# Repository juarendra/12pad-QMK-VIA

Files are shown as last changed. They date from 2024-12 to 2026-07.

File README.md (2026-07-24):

<div align="center">

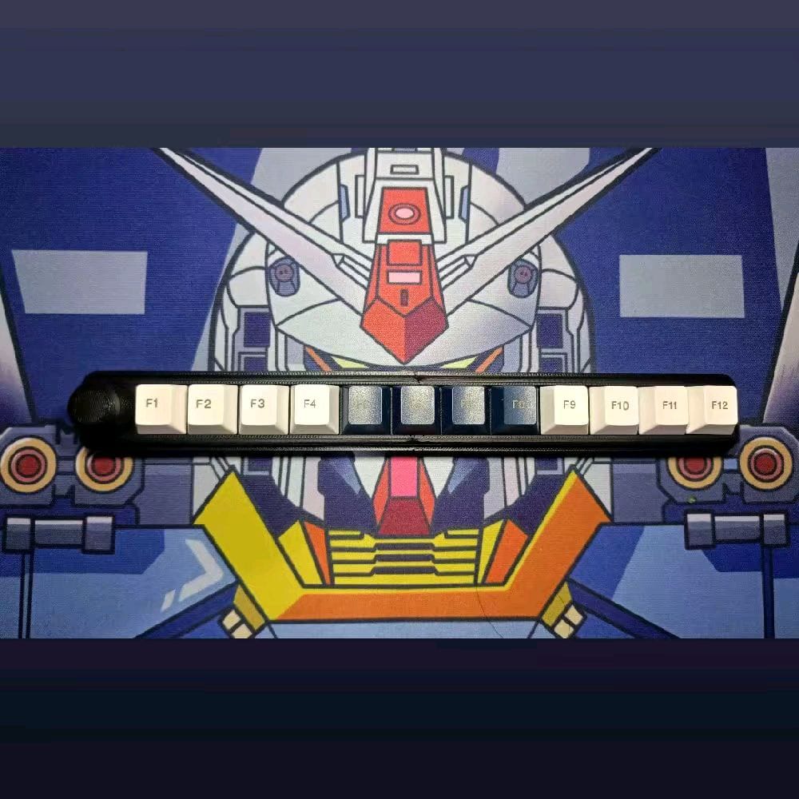
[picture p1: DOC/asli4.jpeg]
Macropad 12pad


# 12pad

**Macropad 12 tombol hotswap + knob putar — semua tombol bisa diprogram lewat VIA, tanpa driver, tanpa coding.**

oleh [Positron Electronic](https://github.com/juarendra)







[⬇️ Unduh Firmware](https://github.com/juarendra/12pad-QMK-VIA/releases/latest) ·
[📖 Buku Panduan](DOC/Buku%20Panduan%2012pad.pdf) ·
[🎛️ Buka VIA](https://usevia.app) ·
[🔌 Wiring](DOC/WIRING%20MACROPAD%2012PAD%20BY%20POSITRON%20ELEKTRONIK.drawio.pdf)

</div>

---

## ✨ Fitur

| | |
|---|---|
| ⌨️ **12 tombol hotswap** | Ganti switch tanpa solder |
| 🎚️ **Knob rotary encoder** | Putar = scroll/volume, tekan = pindah layer — bebas diatur |
| 🌈 **RGB per tombol** | 40+ efek, atur dari VIA atau langsung dari macropad (Layer 5) |
| 🧠 **6 layer × 32 macro** | Profil per aplikasi, tersimpan di dalam macropad |
| 🔧 **QMK + VIA** | Atur keymap real-time di [usevia.app](https://usevia.app), tanpa install apa pun |
| 🔌 **STM32F401 · USB-C** | WeAct Blackpill, identitas USB resmi `0x1209:0x2012` |

<div align="center">
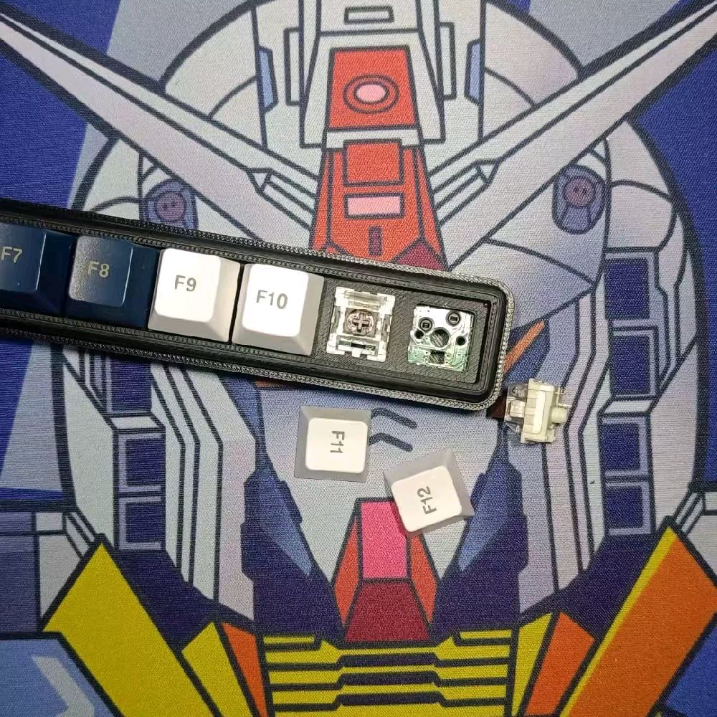
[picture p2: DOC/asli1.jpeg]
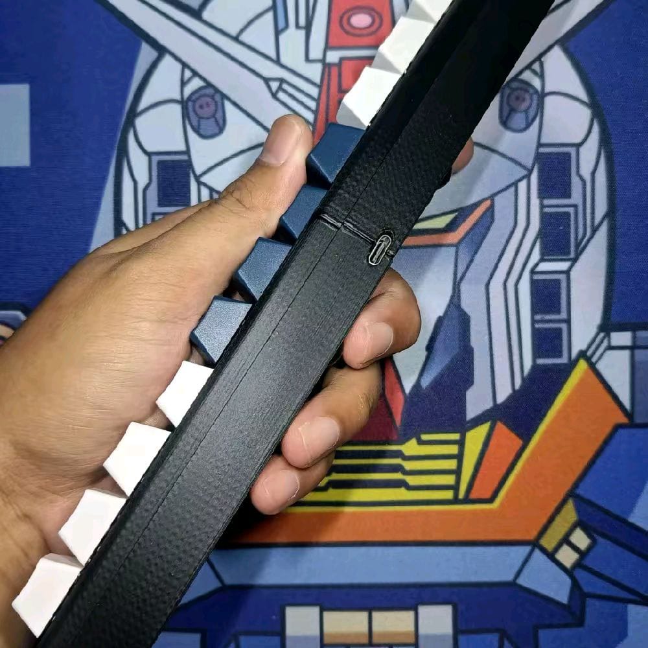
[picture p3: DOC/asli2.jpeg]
 
</div>

## 🚀 Mulai dalam 3 langkah

1. **Colok USB-C** — langsung dikenali sebagai keyboard, tanpa driver
2. **Buka [usevia.app](https://usevia.app)** di Chrome/Edge (internet menyala)
3. **Klik & atur** — pilih tombol di layar, ganti fungsinya, tersimpan otomatis di macropad

> VIA belum mendeteksi? Lihat [Load JSON File](#-load-json-file-sideload) di bawah.

📖 Panduan lengkap (peta layer, macro, RGB, troubleshooting): **[Buku Panduan 12pad (PDF)](DOC/Buku%20Panduan%2012pad.pdf)**

## ⌨️ Keymap bawaan

Tekan knob untuk berpindah layer (0 → 1 → … → 5 → 0).

| Layer | Isi |
|---|---|
| **0** | `F1`–`F12` — siap dipetakan ke shortcut aplikasi · putar knob = Page Up/Down |
| **1–4** | Kosong (transparan) — kanvas bebas untuk profil per aplikasi |
| **5** | Panel kontrol RGB: on/off, efek, kecepatan, saturasi, hue, kecerahan |

## 📦 Firmware

**Unduh siap pakai:** [**Releases — versi terbaru**](https://github.com/juarendra/12pad-QMK-VIA/releases/latest)

| File | Untuk |
|---|---|
| `handwired_positron_12pad_via.bin` | ✅ **Pengguna STM32F401** — VIA aktif |
| `handwired_positron_12pad_default.bin` | STM32F401, keymap default tanpa VIA |
| `12pad_rp2040_default.uf2` | Varian RP2040 |

<details>
<summary><b>Cara flash (STM32)</b></summary>

1. Masuk bootloader: cabut USB, **tahan knob**, colok USB — atau tahan tombol `BOOT0` di board saat colok USB
2. Buka [QMK Toolbox](https://github.com/qmk/qmk_toolbox/releases) → Open file `.bin` → **Flash**

Atau lewat terminal:

```sh
dfu-util -a 0 -d 0483:df11 -s 0x08000000:leave -D handwired_positron_12pad_via.bin
```

Setelah flash, identitas USB berubah menjadi **"Positron Electronic 12pad"** — load ulang `12pad_via_definitions.json` terbaru di VIA bila sebelumnya pernah sideload.
</details>

<details>
<summary><b>Build dari source</b></summary>

Source keyboard: [`FIRMWARE/handwired/positron/12pad/`](FIRMWARE/handwired/positron/12pad). Salin ke `qmk_firmware/keyboards/handwired/positron/12pad`, lalu:

```sh
qmk compile -kb handwired/positron/12pad -km via
```

Setiap push ke folder firmware juga dibuild otomatis oleh [GitHub Actions](https://github.com/juarendra/12pad-QMK-VIA/actions) — unduh `.bin` dari artifact.
</details>

## 🎛️ VIA

### Auto detect
Colok macropad → buka [usevia.app](https://usevia.app) atau [aplikasi VIA](https://github.com/the-via/releases/releases) dengan internet aktif → terdeteksi otomatis.

### 📂 Load JSON File (sideload)
Kalau belum terdeteksi (definisi resmi masih dalam proses):

1. Colok macropad, buka VIA
2. Tab **Settings** → aktifkan **Show Design Tab**
3. Tab **Design** → **Load** file [`12pad_via_definitions.json`](12pad_via_definitions.json)
4. Buka tab **Configure** — siap diatur
5. Masih "searching"? Cabut-colok USB, ulangi dari langkah 3

### 🎚️ Setting knob
Knob tampil sebagai 3 "tombol" di VIA: putar kiri · tekan · putar kanan. Untuk kombinasi khusus pakai **Any** (kategori Special) dengan keycode QMK:

| Keycode | Hasil |
|---|---|
| `LALT(KC_TAB)` | Alt + Tab |
| `LCTL(KC_C)` | Ctrl + C |
| `LSFT(LCTL(KC_END))` | Shift + Ctrl + End |
| `MT(MOD_RSFT, KC_ENT)` | Tahan = Shift, ketuk = Enter |
| `MO(1)` / `TO(2)` | Pindah layer sementara / permanen |
| `M0` … `M31` | Jalankan macro |

Referensi: [Keycode QMK](https://docs.qmk.fm/keycodes) · [Panduan VIA](https://docs.keeb.io/via) · [Macro VIA (PDF)](DOC/MACRO%20VIA%20USAGE.pdf) · [Video tutorial](https://youtu.be/GtSeo69Y0Zw)

## 🛠️ Hardware

- [Dimensi (PDF)](HARDWARE/12pad_dimension.pdf) · [Model 3D STEP](HARDWARE/12pad.step)
- [Case 3D-printable (STL)](HARDWARE/case) — top & bottom, tersedia versi terbelah 2 untuk printer kecil
- [Wiring diagram](DOC/WIRING%20MACROPAD%2012PAD%20BY%20POSITRON%20ELEKTRONIK.drawio.pdf)

## 🗺️ Status Pendaftaran Resmi

| Tahap | Status |
|---|---|
| USB VID/PID `0x1209:0x2012` — [pid.codes #1249](https://github.com/pidcodes/pidcodes.github.com/pull/1249) | ✅ checks lulus, menunggu merge |
| QMK upstream — [qmk_firmware #26362](https://github.com/qmk/qmk_firmware/pull/26362) | ✅ CI lulus, menunggu review |
| VIA autodetect global — PR ke [the-via/keyboards](https://github.com/the-via/keyboards) | ⏳ setelah QMK merge (file sudah siap) |

## 📄 License

Firmware dilisensikan di bawah [GPL-2.0](LICENSE).

<div align="center">
<sub>Dibuat dengan ☕ oleh <b>Positron Electronic</b> · Indonesia</sub>
</div>

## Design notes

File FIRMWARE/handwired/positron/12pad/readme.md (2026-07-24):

# 12pad

12-key hotswap macropad with a rotary encoder, by Positron Electronic.

* Keyboard Maintainer: [juarendra](https://github.com/juarendra)
* Hardware Supported: WeAct Blackpill STM32F401 (USB Type-C)
* Hardware Availability: [Positron Electronic](https://github.com/juarendra/12pad-QMK-VIA)

Make example for this keyboard (after setting up your build environment):

    qmk compile -kb handwired/positron/12pad -km default

Flashing:

    qmk flash -kb handwired/positron/12pad -km default

See the [build environment setup](https://docs.qmk.fm/#/getting_started_build_tools) and the [make instructions](https://docs.qmk.fm/#/getting_started_make_guide) for more information. Brand new to QMK? Start with our [Complete Newbs Guide](https://docs.qmk.fm/#/newbs).

## Bootloader

Enter the bootloader in 3 ways:

* **Bootmagic reset**: Hold down the encoder knob (top-left key) and plug in the keyboard
* **Physical reset**: Hold the `BOOT0` button on the Blackpill, tap `NRST` (or plug in USB), then release `BOOT0`
* **Keycode in layout**: Press the key mapped to `QK_BOOT` if it is available

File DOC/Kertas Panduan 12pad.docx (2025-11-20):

1. Untuk Documentasi Lengkapnya anda dapat membuka link google drive dibawah ini

https://github.com/juarendra/12pad-QMK-VIA

Lihat dahulu video untuk mengetahui cara pengunaan macropad dengan software VIA

2. Fungsi file file di google drive
  a. Link Keycode.txt = berisi link yang menunjukan list keycode yang dapat digunakan dalam melakukan setting keymap
  b. TUTORIAL MACRO ON VIA CONFIGURATOR.txt = berisi link tutorial cara membuat macro di software vial
  c. LINK TUTORIAL PENGGUNAAN.txt = berisi link video tutorial penggunaan
  d. TUTORIAL MEMBUAT TOMBOL PINDAH LAYER.txt = berisi panduan untuk merubah fungsi tombol sebagai trigger memindahkan layer

# e. AUTO DETECT VIA

Untuk panduan lainnya menggunakan software via ada dapat membacanya disini https://docs.keeb.io/vi (https://docs.keeb.io/via)a (https://docs.keeb.io/via) (https://docs.keeb.io/via)

Pada via hanya dapat menyimpan maks 15 macro di seluruh layer. Ada beberapa trik untuk memaksimalkannya. Jika macro anda hanya kombinasi sederhana seperti CTRL + ALT + DEL maka anda dapat menggunakan fitur ANY keys pada tab special seperti dibawah

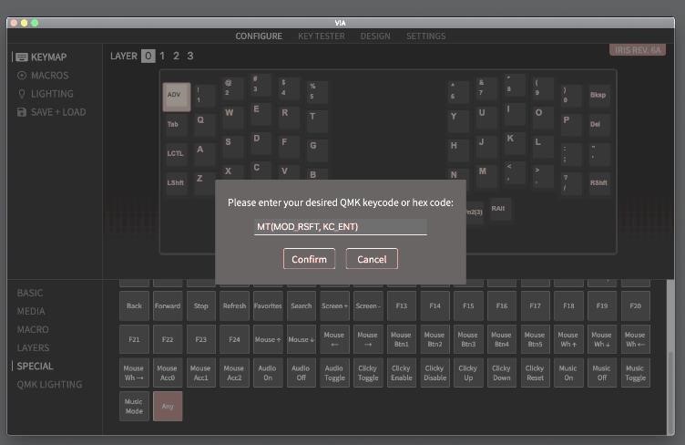
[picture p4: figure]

Untuk jelasnya anda dapat membacanya di https://docs.keeb.io/vi (https://docs.keeb.io/via)a (https://docs.keeb.io/via) (https://docs.keeb.io/via)

Cara Menggunakan Software VIA Pada Macropad

(PADA VERSI INI MACROPAD SUDAH AUTO DETECT PADA VIA JADI CUKUP

MENYALAKAN INTERNET DAN MEMBUKA APPS VIA MAKA AKAN OTOMATIS

TERDETEKSI)

1. Colok dahulu Macropad pada PC
2. Buka Aplikasi VIA
3. Pada Tab Setting , aktifkan “Show Design Tab”
4. Buka Tan Design
5. Load file extension “json” di github yang di berikan (12pad_via_definitions.json)
6. Buka tab Configure untuk melakukan setting
7. Jika masih muncul gambar searching, maka ulangi lagi load json file

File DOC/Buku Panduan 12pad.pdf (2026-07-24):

# 12pad

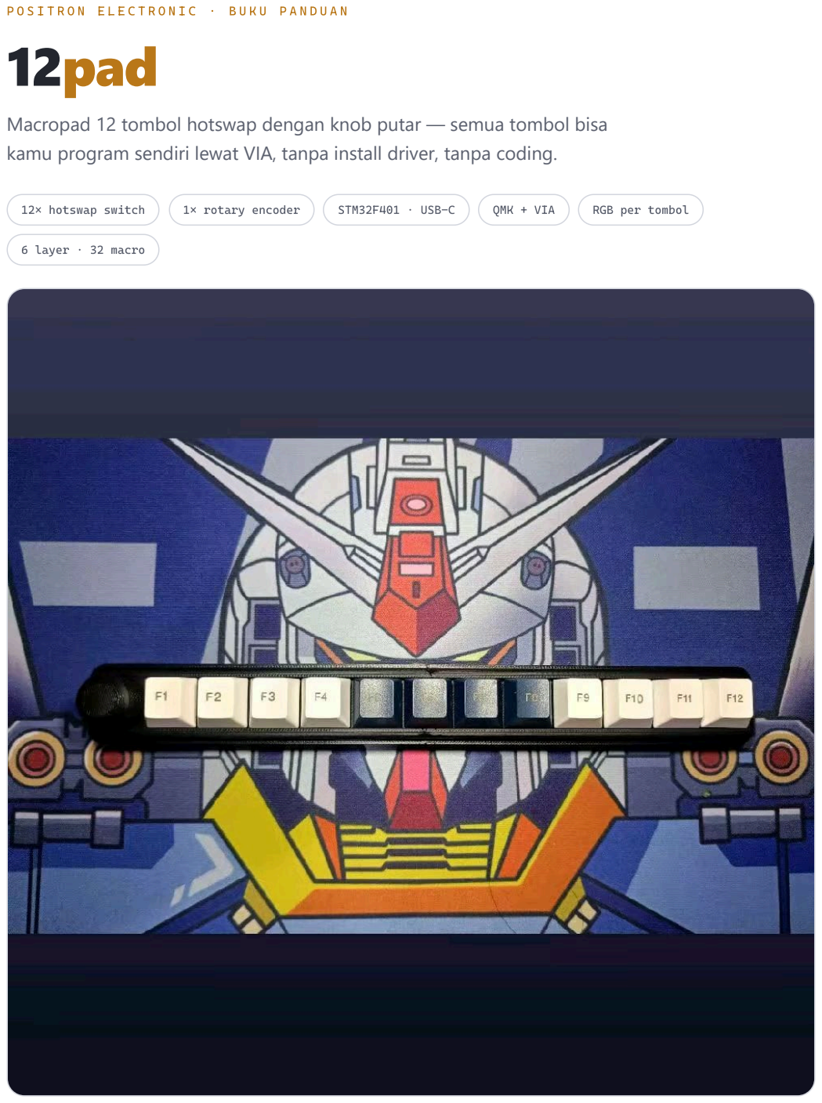
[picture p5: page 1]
12× hotswap switch; 1× rotary encoder; STM32F401 · USB-C; QMK + VIA; RGB per tombol; 6 layer · 32 macro

Macropad 12 tombol hotswap dengan knob putar — semua tombol bisa
kamu program sendiri lewat VIA, tanpa install driver, tanpa coding.

M U L A I | D A L A M | 3 | L A N G K A H

## Langsung pakai, 2 menit

01
Colok USB-C
Hubungkan 12pad ke PC. Tidak perlu driver — langsung dikenali sebagai keyboard.

02
Buka VIA
Kunjungi
usevia.app
di Chrome/Edge, atau install aplikasi VIA. Pastikan internet menyala.

03
Klik & atur
Klik tombol di layar, pilih fungsi baru. Tersimpan langsung di macropad — kesetting terbawa ke PC mana pun.

VIA belum mendeteksi? Ikuti cara "load file JSON" di halaman berikut — sekali load, VIA akan ingat selamanya.

K E N A L I P E R A N G K A T

## Peta tombol bawaan

12pad berbentuk bar satu baris: knob di ujung kiri, lalu 12 tombol dalam tiga kelompok empat. Macropad punya 6 layer — anggap saja 6 "halaman" fungsi. Tekan knob untuk pindah ke layer berikutnya (0 → 1 → … → 5 → kembali ke 0). Tanda ▽ berarti transparan: fungsi mengikuti Layer 0 sampai kamu isi sendiri lewat VIA.

LAYER 0 — bawaan pabrik
F1–F12, siap dipetakan ke shortcut aplikasi. Putaran knob menggulung halaman (Page Up / Page Down) · tekan = ke Layer 1.
Ke Layer 1 | F1
| KC_F1

F2

KC_F2

F3

KC_F3

F4

KC_F4

F5

KC_F5

F6

KC_F6

F7

KC_F7

F8

KC_F8

F9

KC_F9

F10

KC_F10

F11

KC_F11

F12

KC_F12

Layer 1–4: kanvas kosong. Semua tombolnya transparan (▽) — knob tetap berfungsi pindah layer (TO(2), TO(3), TO(4), TO(5)). Isi lewat VIA untuk profil per aplikasi: satu layer untuk editing, satu untuk OBS, satu untuk shortcut kerja, dan seterusnya.

LAYER 5 — panel kontrol RGB
Atur lampu langsung dari macropad. Tekan knob sekali lagi untuk kembali ke Layer 0.

Ke Layer 0

RGB
On/Off

RM_TOGG

Efek →

RM_NEXT

Speed +

RM_SPDU

Speed −

RM_SPDD

Saturasi
+

RM_SATU

Saturasi
−

RM_SATD

Hue +

RM_HUEU

Hue −

RM_HUED

Terang +

RM_VALU

Terang −

RM_VALD

TO(1) TO(0)

▽

KC_TRNS

▽

KC_TRNS

H U B U N G K A N | K E | V I A

## Kalau perlu load manual (sideload)

Sebelum definisi resmi tayang di server VIA, load file JSON sekali saja:

K U S T O M I S A S I

## Mengatur tombol & knob

Klik tombol mana pun di VIA lalu pilih fungsi dari daftar bawah. Untuk kombinasi khusus (dan untuk knob), pakai Any di kategori Special, lalu ketik keycode QMK:

K E Y C O D E | H A S I L
LALT(KC_TAB) | Alt + Tab — ganti jendela
LCTL(KC_C) | Ctrl + C — copy
LGUI(KC_V) | Win + V — riwayat clipboard
LSFT(LCTL(KC_END)) | Shift + Ctrl + End — blok sampai akhir
LCA(KC_DEL) | Ctrl + Alt + Del
MT(MOD_RSFT, KC_ENT) | Tahan = Shift, ketuk = Enter
MO(1) | Pindah ke layer 1 selama ditahan
TO(2) | Pindah permanen ke layer 2
M0 … M31 | Jalankan macro 0–31

Daftar lengkap: docs.qmk.fm/keycodes · panduan VIA: docs.keeb.io/via

Khusus knob (rotary encoder)

Di VIA, knob tampil sebagai tiga "tombol": putar kiri, tekan, putar kanan. Klik lalu isi seperti tombol biasa — misal putar kiri/kanan = KC_VOLD / KC_VOLU untuk volume, tekan = KC_MUTE .

1 Colok 12pad ke PC, buka aplikasi VIA / usevia.app.

2 Masuk tab Settings, aktifkan Show Design Tab.

3 Buka tab Design (ikon kuas).

4 Klik Load, pilih file 12pad_via_definitions.json (unduh dari github.com/juarendra/12pad-QMK-VIA).

5 Buka tab Configure — 12pad siap diatur.

6 Masih muncul animasi "searching"? Cabut-colok USB lalu ulangi dari langkah 3.

O T O M A S I

## Macro: satu tombol, banyak aksi

Firmware ini menyimpan hingga 32 macro di dalam macropad — mengetik teks, kombinasi tombol beruntun, sampai shortcut aplikasi.

Hemat slot macro. Kombinasi sederhana seperti Ctrl+Alt+Del tidak perlu macro — cukup keycode LCA(KC_DEL) lewat tombol Any. Simpan slot macro untuk urutan yang benar-benar panjang.

P E N C A H A Y A A N

## Lampu RGB

Atur dari VIA: panel Lighting menyediakan kecerahan, 40+ efek, kecepatan, dan warna. Atau langsung dari macropad lewat Layer 5 (lihat peta tombol di atas). Pengaturan tersimpan otomatis.

P E R A W A T A N

## Update firmware

Perlu sesekali saja — misalnya saat ada fitur baru. Unduh file positron_12pad_via.bin dari GitHub, lalu:

Pengguna terminal bisa memakai dfu-util:

dfu-util -a 0 -d 0483:df11 -s 0x08000000:leave -D positron_12pad_via.bin

Setelah update ke firmware baru, identitas USB berubah menjadi "Positron Electronic 12pad" (VID 0x1209 / PID 0x2012). Kalau VIA sempat kamu sideload dengan file lama, load ulang 12pad_via_definitions.json versi terbaru.

1 Di VIA, buka panel Macros di sisi kiri tab Configure.

2 Pilih slot (M0–M31), klik ikon pensil untuk mode edit.

3 Ketik teks yang mau dikirim, atau klik ikon keyboard untuk merekam penekanan tombol.

4 Klik Save, lalu pasang macro ke tombol: kategori Macro → pilih M0 – M31 .

Masuk mode bootloader. Cabut USB, tahan knob, colok USB sambil knob masih ditahan (atau: tahan tombol BOOT0 di board, colok USB, lepas).

1

2 Buka QMK Toolbox — status akan menampilkan "STM32 DFU device connected".

3 Open file .bin yang diunduh, pastikan MCU STM32F401 .

4 Klik Flash, tunggu "Flash complete", cabut-colok USB. Selesai.

B A N T U A N

## Ada kendala?

G E J A L A | S O L U S I
VIA tidak mendeteksi macropad | Pastikan internet aktif, pakai Chrome/Edge di usevia.app. Masih gagal → sideload JSON.
Muncul "searching…" terus di VIA | Cabut-colok USB, ulangi load JSON dari tab Design.
Tombol berubah semua / layer "nyasar" | Kamu mungkin tidak sengaja menekan knob. Tekan knob beberapa kali sampai kembali ke Layer 0 (cek angka layer di VIA).
Macro tidak jalan | Pastikan tombol diisi M0 – M31 sesuai slot yang kamu isi di panel Macros, dan macro sudah di-Save.
Setelah update firmware, VIA tidak kenal | Load ulang file 12pad_via_definitions.json terbaru (identitas USB berubah).
Macropad tidak merespons sama sekali | Coba kabel/port lain. Masih diam → flash ulang firmware (bagian Update Firmware).
© Positron Electronic · Firmware open source (GPL-2.0) | github.com/juarendra/12pad-QMK-VIA · usevia.app · docs.qmk.fm/keycodes

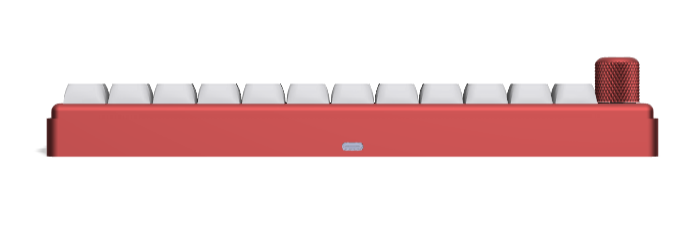
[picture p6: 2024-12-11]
DOC/12pad2.png

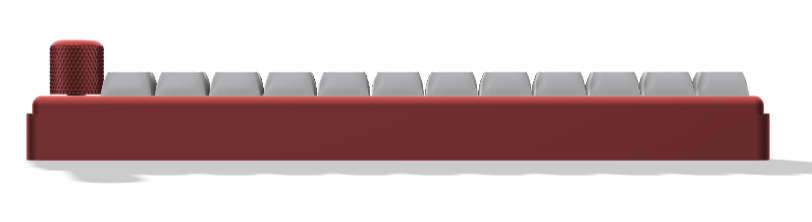
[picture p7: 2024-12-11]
DOC/12pad1.png

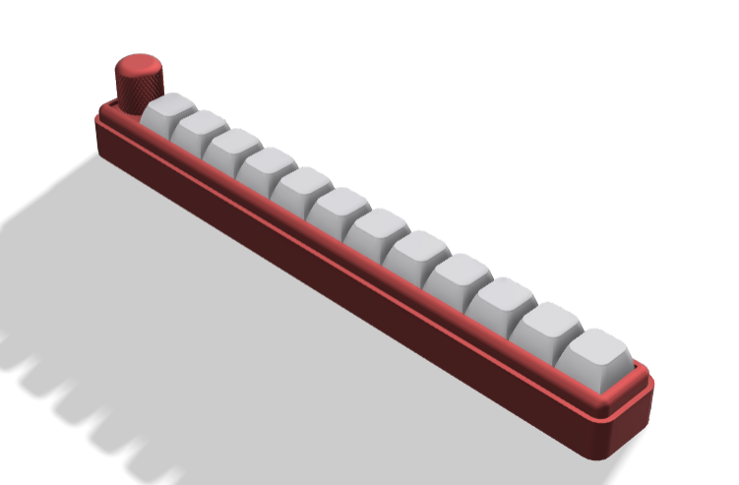
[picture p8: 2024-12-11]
DOC/12pad.png

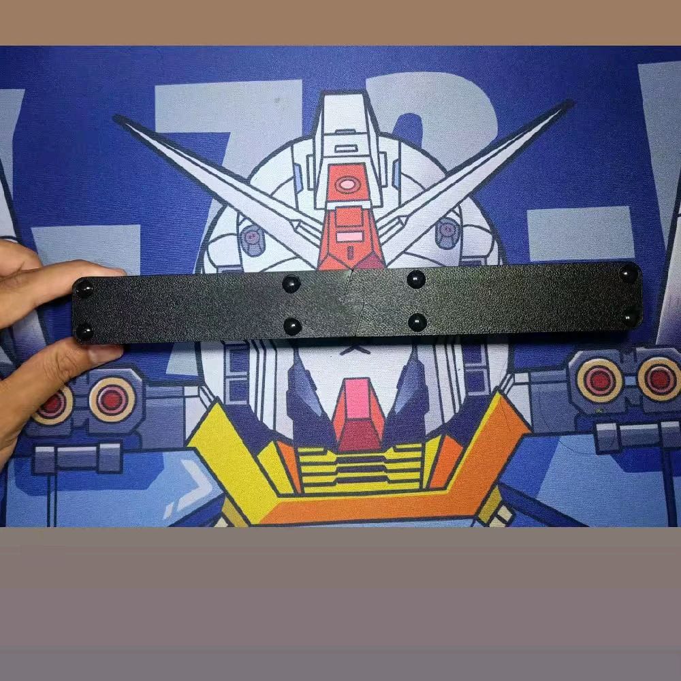
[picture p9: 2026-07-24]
DOC/asli3.jpeg

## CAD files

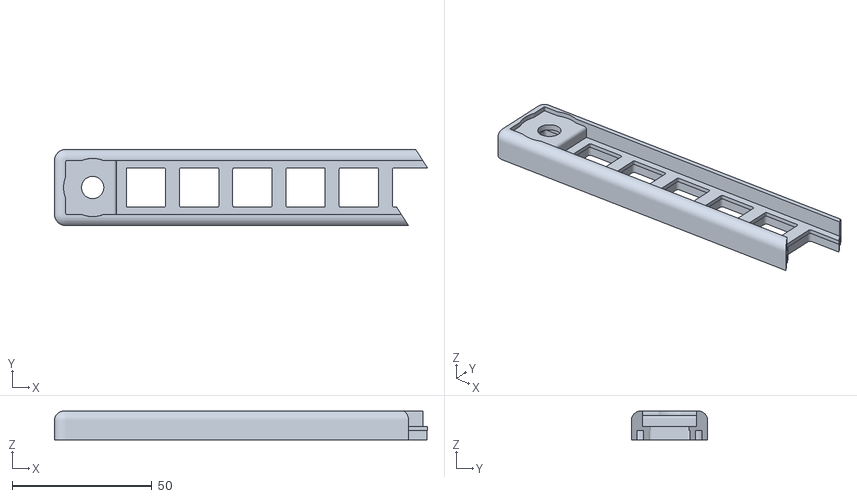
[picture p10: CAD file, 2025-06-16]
HARDWARE/case/12pad_top_1.stl
133.5 x 27.3 x 10.3

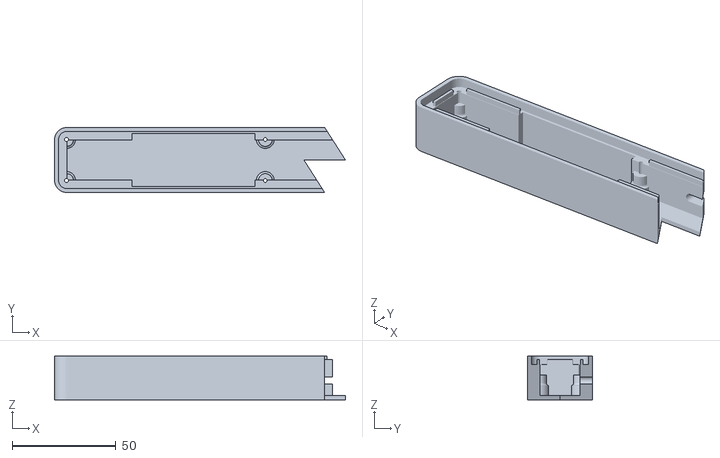
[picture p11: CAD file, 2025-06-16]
HARDWARE/case/12pad_bottom_2.stl
140.0 x 31.3 x 21.0

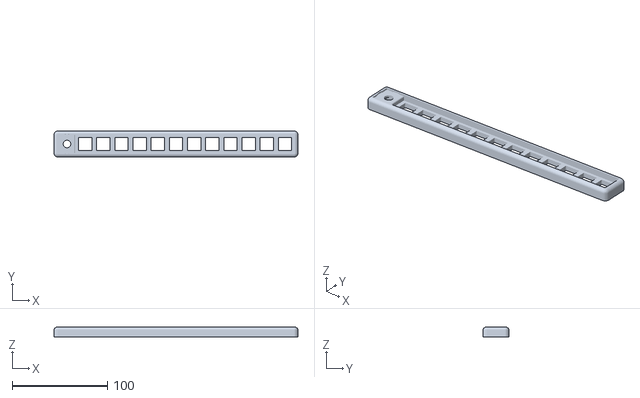
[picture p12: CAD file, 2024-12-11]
HARDWARE/case/12pad_top.stl
255.9 x 27.3 x 10.3

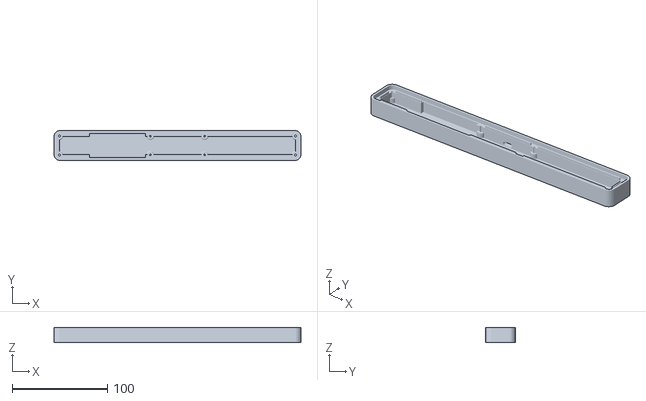
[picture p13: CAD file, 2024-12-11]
HARDWARE/case/12pad_bottom.stl
259.9 x 31.3 x 16.0

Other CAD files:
HARDWARE/case/12pad_top_2.stl
HARDWARE/case/12pad_bottom_1.stl

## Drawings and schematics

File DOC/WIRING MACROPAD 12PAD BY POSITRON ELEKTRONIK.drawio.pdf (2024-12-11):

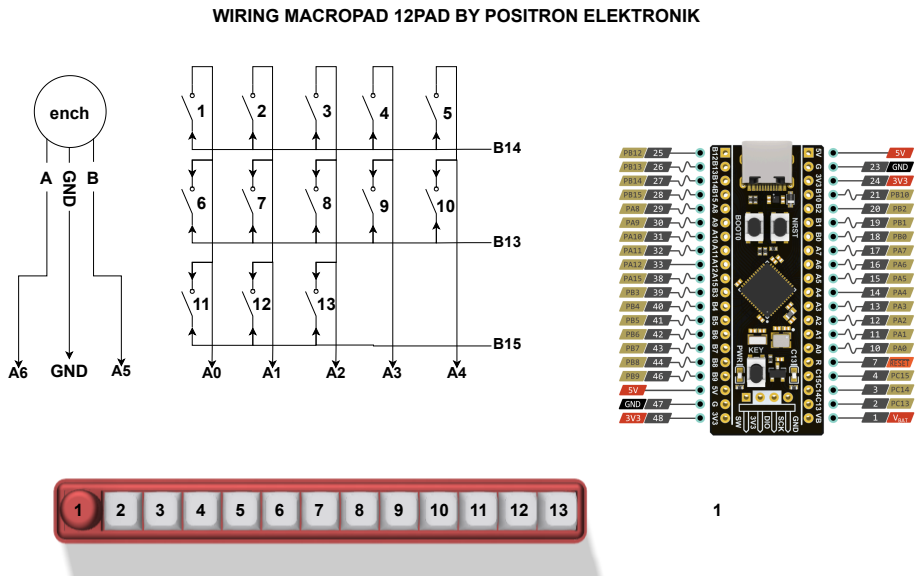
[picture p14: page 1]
ench; A B GND; GND

WIRING MACROPAD 12PAD BY POSITRON ELEKTRONIK

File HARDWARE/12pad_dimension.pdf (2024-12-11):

27.4 ¹⁸.97 255.9 | 259.9 27.3 | 31.3 259.9

# 31.3 Ø8.3 Ø4 2 Ø

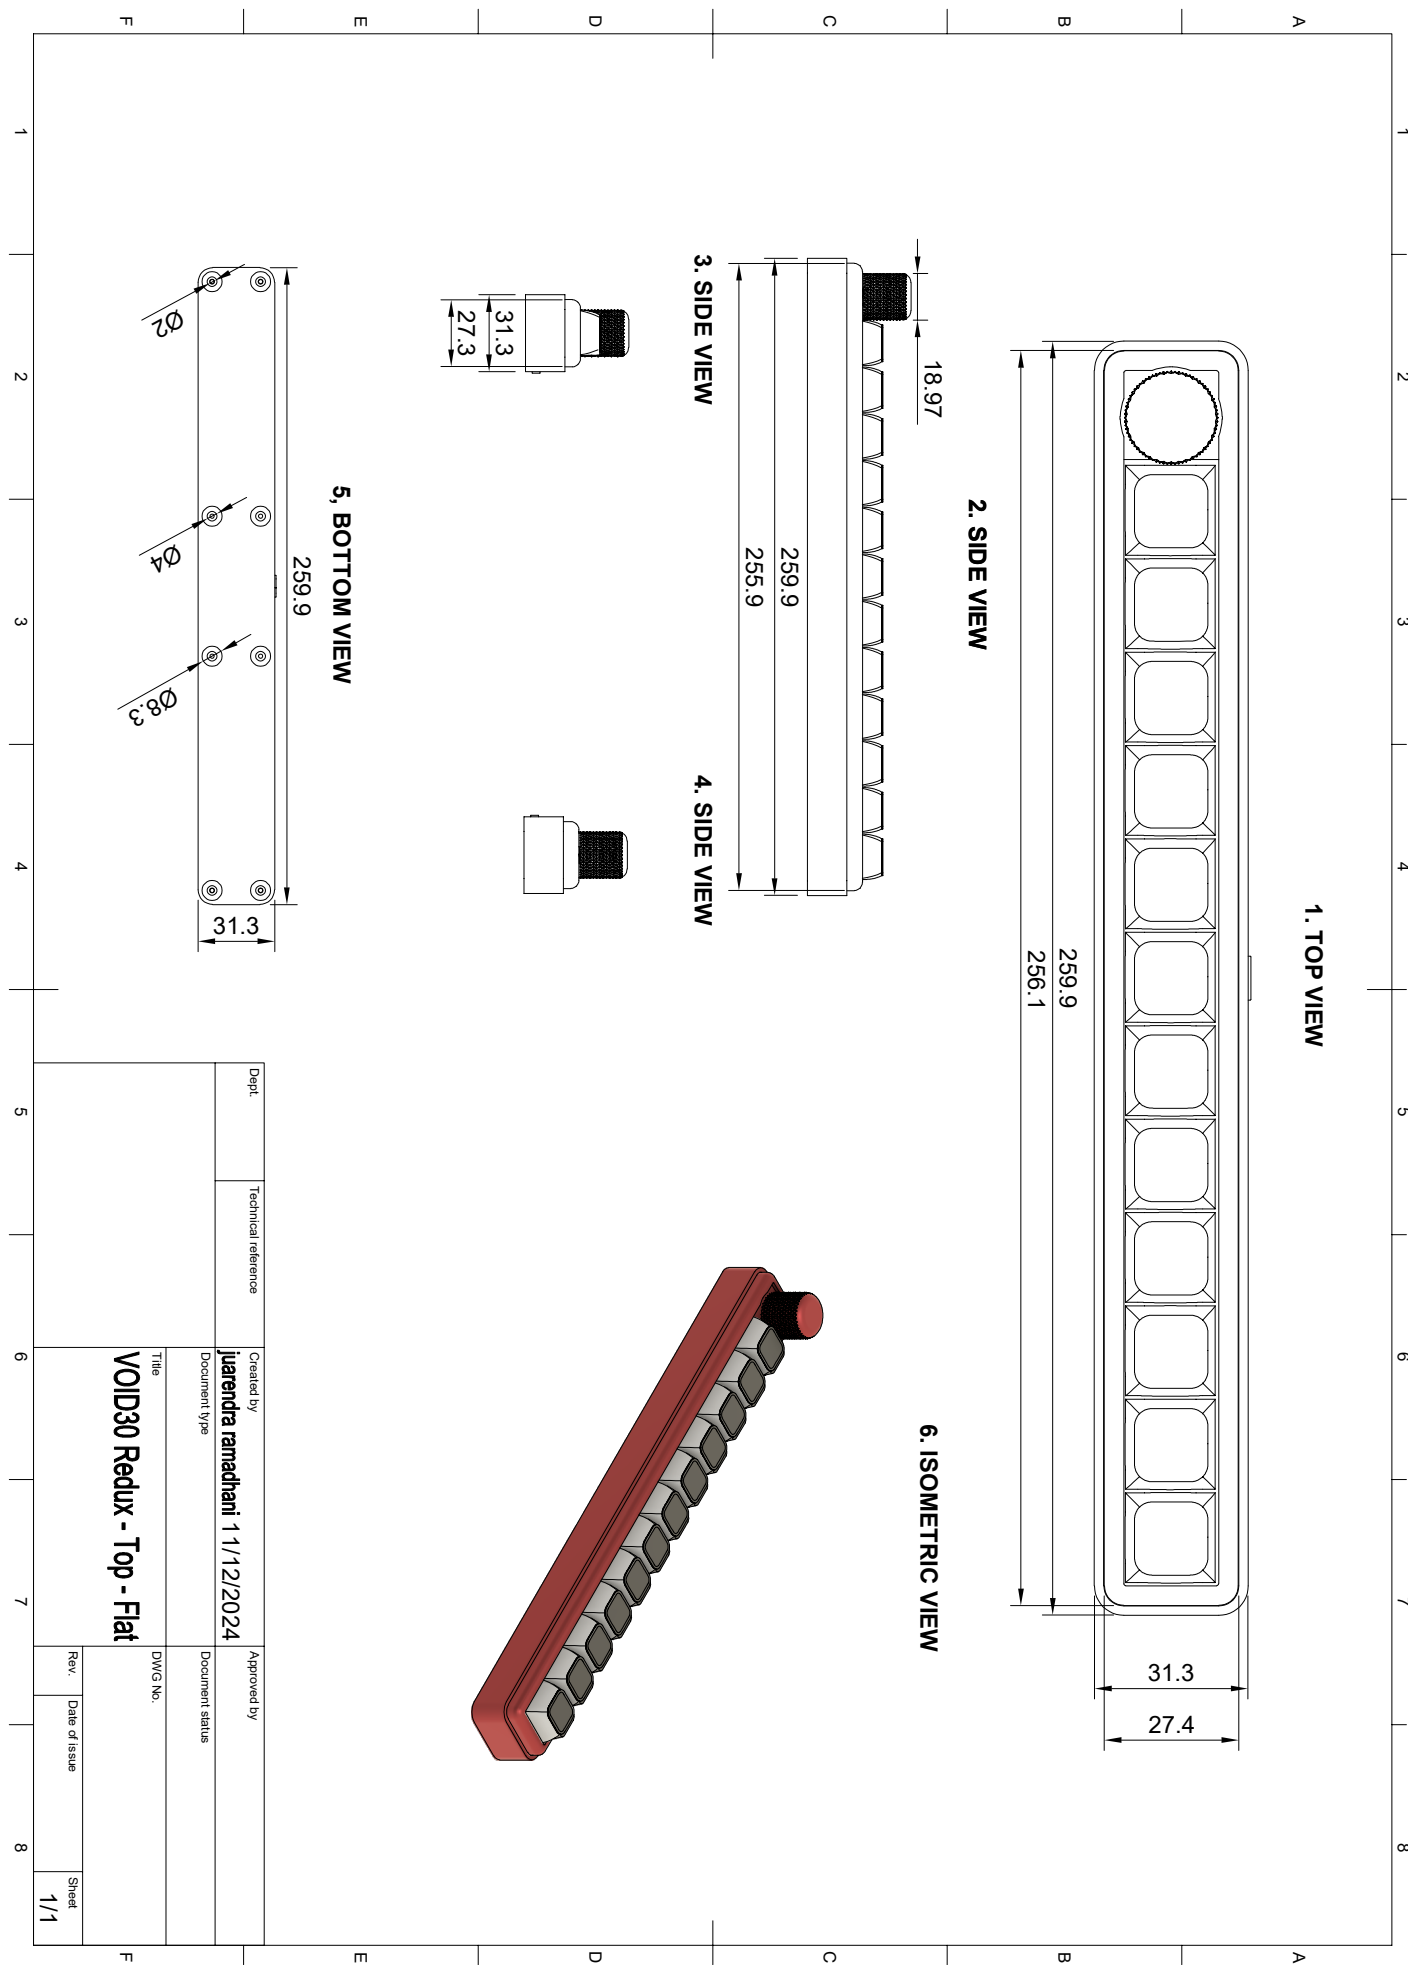
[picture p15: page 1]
31.3 ²⁵⁶.1

1 A 2 3 4 5 6 7 8 1 2 3 4 5 6 7 8 FEDCB FEDCBA Dept. Technical reference Created by Approved by Title DWG No. Document type Document status Rev. Date of issue Sheet 11/12/2024 1/1 1. TOP VIEW 2. SIDE VIEW 3. SIDE VIEW 4. SIDE VIEW 5, BOTTOM VIEW 6. ISOMETRIC VIEW 259.9

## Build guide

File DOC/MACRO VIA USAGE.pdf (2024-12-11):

MACRO
Pada VIA memiliki space yang terbatas atau jumlah macro yang tebatas. Maka dari itu untuk memaksimalkan penggunaan, anda dapat menggunkan Fitur Any Key jika macro anda hanya terdiri dari kombinasi yang sederhana. Untuk saat ini tidak ada batasan pada penggunaan Fitur Any Key
- MACRO NORMAL
Jika anda akan membuat macro dengan kombinasi yang rumit, anda dapat menggunakan macro yang ada pada tab/menu MACRO seperti gambar dibawah.
Macro Recorder

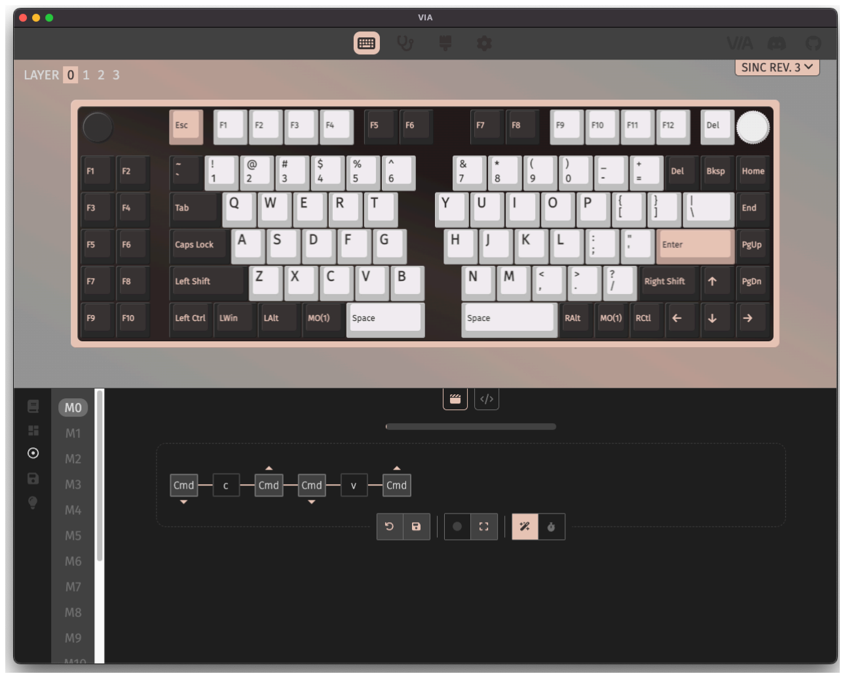
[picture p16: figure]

Metode ini memungkinkan Anda merekam makro, alih-alih mencoba mengetikkan kode kunci secara manual.
Keycode Entry

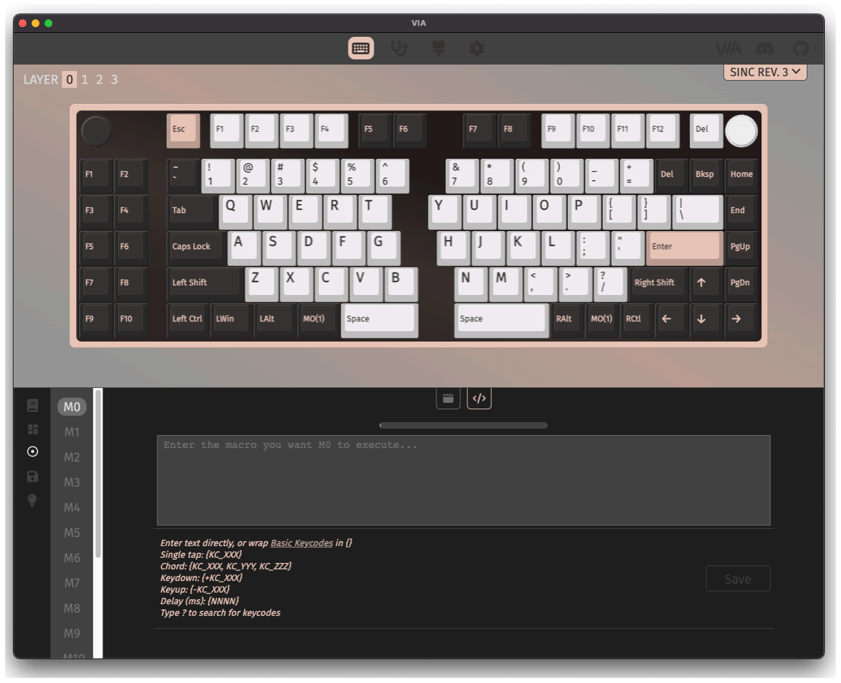
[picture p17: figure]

Anda bisa mengetik teks secara langsung tanpa harus mengetahui apa pun tentang nama keycodei QMK, atau jika Anda memasukkan sesuatu ke dalam tanda kurung kurawal ({}), Anda bisa menggunakan kode kunci QMK dasar.

Beberapa istilah yang perlu diketahui

MO (lapisan): Ini mengaktifkan lapisan ketika ditekan dan Anda kembali ke lapisan sebelumnya ketika Anda melepaskan kunci. Mirip dengan tombol Shift dan Fn dalam pengoperasiannya.

LM(layer, modifier): Ini mengaktifkan lapisan dan juga akan mempertahankan pengubah untuk Anda saat ditekan.

LT(lapisan, kode kunci): Tekan ini dan tahan untuk mengaktifkan lapisan dan mengirimkan kode kunci ketika diketuk sebentar. Penggunaan terbaik untuk tombol yang biasanya hanya Anda tekan dengan cepat seperti Tab atau Spasi.

Contoh Makro
MyPassw0rd! - Mengirim MyPassw0rd!
{KC_A,KC_C,KC_E} - Mengirim kartu as
{KC_LCTL,KC_C} - Mengirim Ctrl-C
- Any Key
Any Key dapat digunakan untuk melakukan beberapa kode kunci yang lebih kompleks, seperti yang melibatkan pengubah, lapisan, atau tombol ketuk mod. Anda juga dapat memasukkan kode kunci biasa di sini jika Anda mau.

Tidak semua alias didukung, misalnya LCTL_T(kc) tidak dapat digunakan, jadi MT(MOD_LCTL, kc) harus digunakan.

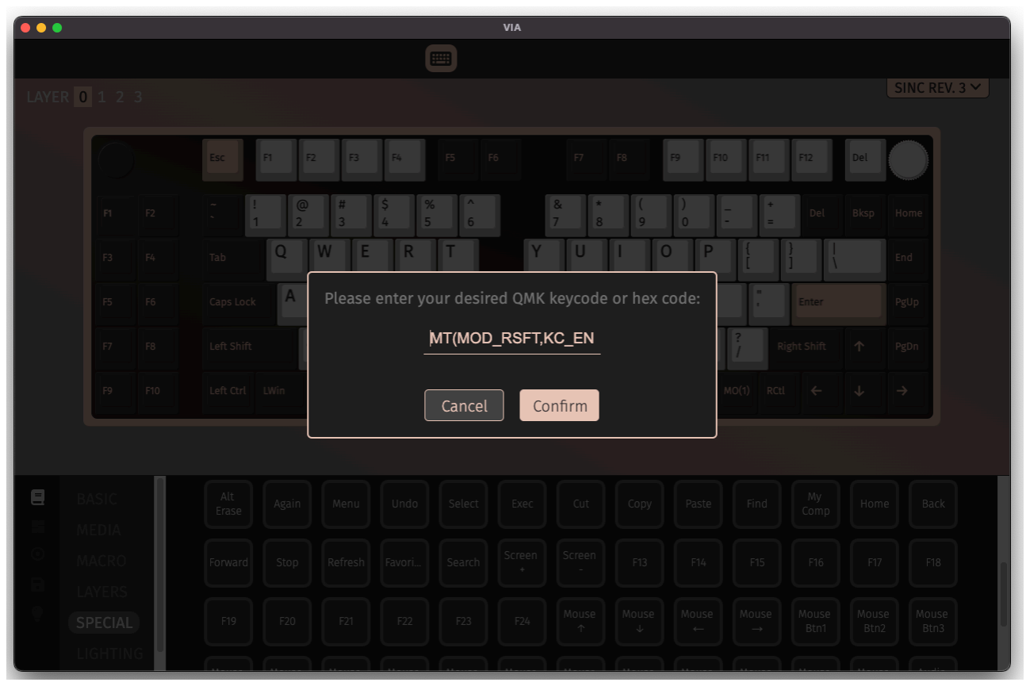
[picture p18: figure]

Here's some examples:

LALT(KC_TAB) - Sends Alt-Tab
LCTL(KC_C) - Sends Ctrl-C
LGUI(KC_C) - Sends Cmd-C or Win-C LSFT(LCTL(KC_END)) - Sends Shift-Ctrl-End
MO(1) - Momentarily turn on layer 1
LCA(KC_DEL) - Sends Ctrl-Alt-Del
MT(MOD_RSFT, KC_ENT) - Sends Shift if held, Enter if tapped QMK Lighting

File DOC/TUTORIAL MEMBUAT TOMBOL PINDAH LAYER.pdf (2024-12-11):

1. Buka App VIA Configurator
2. Masukan File JSON keymap yang ada di google drive
3. Hubungkan Macropad ke PC
4. Buka Tab Configure
5. Pada Tab Configure pilih Tab Layer
6. Tentukan 1 Tombol yang akan digunakan untuk perpindahan layer
7. Ketika baru pertama dihubungkan ke PC maka macropad otomatis berada pada layer 0,
8. Klick tombol tersebut dan ganti fungsi menjadi TO1(isi dari tab layer), ini artinya fungsi tombol tersebut adalah memidahkan layer sekarang ke layer 1
9. Pindah ke layer 1, lalu klick tombol tersebut lagi dan ganti fungsi menjadi TO2(isi dari tab layer), ini artinya fungsi tombol tersebut adalah memidahkan layer sekarang ke layer 2 10.Pindah ke layer 2, lalu klick tombol tersebut lagi dan ganti fungsi menjadi TO3(isi dari tab layer), ini artinya fungsi tombol tersebut adalah memidahkan layer sekarang ke layer 3
11. Pindah ke layer 3, lalu klick tombol tersebut lagi dan ganti fungsi menjadi TO0(isi dari tab layer), ini artinya fungsi tombol tersebut adalah memindahkan layer sekarang kembali lagi ke layer 0
12. Selesai

layer 0 ----> layer 1 ----> layer 2 ----> layer 3 ----> layer 0
TO1 | TO2 | TO3 | TO0

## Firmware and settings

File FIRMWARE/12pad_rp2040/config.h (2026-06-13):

#pragma once
#define DYNAMIC_KEYMAP_MACRO_COUNT 32
#define DEBOUNCE 5

#define ENCODERS_PAD_A {GP12}
#define ENCODERS_PAD_B {GP13}
#define ENCODER_DIRECTION_FLIP
#define ENCODER_RESOLUTIONS {4}

#define WS2812_DI_PIN GP23 //D3 - underglow C7 - backlight
#define RGBLED_NUM 6    // Number of L
#define MIDI_BASIC

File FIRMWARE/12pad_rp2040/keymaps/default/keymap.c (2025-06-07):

#include QMK_KEYBOARD_H


enum layer_names {
    _LAY0,
    _LAY1,
    _LAY2,
    _LAY3,
    _LAY4,
    _LAY5
};

const uint16_t PROGMEM keymaps[][MATRIX_ROWS][MATRIX_COLS] = {
  [_LAY0] = LAYOUT(
		TO(1), KC_F1,   KC_F2,   KC_F3,   KC_F4,      KC_F5,   KC_F6,   KC_F7,   KC_F8,      KC_F9,   KC_F10,  KC_F11,  KC_F12),
  [_LAY1] = LAYOUT(
		TO(2), KC_TRNS, KC_TRNS, KC_TRNS, KC_TRNS,    KC_TRNS, KC_TRNS, KC_TRNS, KC_TRNS,    KC_TRNS, KC_TRNS, KC_TRNS, KC_TRNS),
  [_LAY2] = LAYOUT(
		TO(3), KC_TRNS, KC_TRNS, KC_TRNS, KC_TRNS,    KC_TRNS, KC_TRNS, KC_TRNS, KC_TRNS,    KC_TRNS, KC_TRNS, KC_TRNS, KC_TRNS),
  [_LAY3] = LAYOUT(
		TO(4), KC_TRNS, KC_TRNS, KC_TRNS, KC_TRNS,    KC_TRNS, KC_TRNS, KC_TRNS, KC_TRNS,    KC_TRNS, KC_TRNS, KC_TRNS, KC_TRNS),
  [_LAY4] = LAYOUT(
		TO(5), KC_TRNS, KC_TRNS, KC_TRNS, KC_TRNS,    KC_TRNS, KC_TRNS, KC_TRNS, KC_TRNS,    KC_TRNS, KC_TRNS, KC_TRNS, KC_TRNS),
  [_LAY5] = LAYOUT(
		TO(1), KC_F1,   KC_F2,   KC_F3,   KC_F4,      KC_F5,   KC_F6,   KC_F7,   KC_F8,      KC_F9,   KC_F10,  KC_F11,  KC_F12)

};

#ifdef ENCODER_MAP_ENABLE
const uint16_t PROGMEM encoder_map[][NUM_ENCODERS][NUM_DIRECTIONS] = {
    [_LAY0] = { ENCODER_CCW_CW(KC_PGUP, KC_PGDN) },
    [_LAY1] = { ENCODER_CCW_CW(KC_TRNS, KC_TRNS) },
    [_LAY2] = { ENCODER_CCW_CW(KC_TRNS, KC_TRNS) },
    [_LAY3] = { ENCODER_CCW_CW(KC_TRNS, KC_TRNS) },
    [_LAY4] = { ENCODER_CCW_CW(KC_TRNS, KC_TRNS) },
    [_LAY5] = { ENCODER_CCW_CW(KC_TRNS, KC_TRNS) },
};
#endif

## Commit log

2024-12-11 FEAT: add wiring pdf
2025-06-14 FIX: fix bug macro is gone
    [config.h]
2025-06-16 FEAT: add case with devided 2 pieces
    [12pad_bottom_1.stl, 12pad_bottom_2.stl, 12pad_top_1.stl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]
2026-07-24 fix(12pad): remove wrong MATRIX_ROWS/COLS defines
    Matrix size is derived from matrix_pins in keyboard.json (3x5).
    Manual MATRIX_COLS 10 conflicted with the real 5 columns and
    wasted dynamic keymap EEPROM space.
    [config.h]
2026-07-24 chore(12pad): drop unused I2C/PWM peripheral overrides
    mcuconf.h enabled I2C1 and TIM5 PWM and halconf.h enabled the I2C/PWM
    HAL, but nothing uses them: there is no I2C device and the ws2812
    driver runs in default bitbang mode on A10 (TIM5 could not serve A10
    anyway). Board defaults are sufficient.
2026-07-24 docs(12pad): add build and DFU flash instructions
    The rp2040 variant had a README but the STM32 variant had none;
    users had no documented way to build or flash it.
2026-07-24 ci: build STM32 firmware on push
    Compiles 12pad:default against qmk_firmware master in the official
    qmk_cli container and uploads the .bin as an artifact, so users can
    download flashable firmware without a local toolchain.
2026-07-24 build: add prebuilt STM32 firmware binary
    Compiled by CI (run 30107143704) against qmk_firmware master.
    Lets users flash via DFU without a local toolchain, matching the
    prebuilt binaries already shipped for the rp2040 variant.
2026-07-24 refactor(12pad)!: restructure as positron/12pad for QMK upstream
    - move keyboard to positron/12pad vendor folder
    - switch to data-driven development_board: blackpill_f401
    - move shared endpoint config into keyboard.json
    - split VIA into keymaps/via (QMK rule: no VIA_ENABLE at keyboard
    level), default keymap stays VIA-free
    - move DYNAMIC_KEYMAP_MACRO_COUNT to the via keymap
    - move ENCODER_MAP_ENABLE to keymap level
    BREAKING CHANGE: build target is now positron/12pad; plain
    12pad:default no longer exists.
    [config.h, keymap.c]
2026-07-24 feat!: adopt own USB identity 0x1209:0x2012
    VID/PID previously collided with another product, so VIA matched the
    wrong definition. New identity requested from pid.codes (PR #1249),
    manufacturer string standardized to "Positron Electronic".
    BREAKING CHANGE: devices flashed with the new firmware no longer
    match VIA definitions sideloaded for 0xD010:0x1201; use the updated
    12pad_via_definitions.json.
2026-07-24 docs: add official registration roadmap (pid.codes, QMK, VIA)
2026-07-24 docs: use real product photos, fix keymap diagram to single-row bar
    README hero and feature shots now use actual photos (DOC/asli*.jpeg).
    Manual PDF adds the product photo and corrects the key diagram: the
    device is a one-row bar (knob + 4-4-4 keys), not a 4x3 grid.
2026-07-24 refactor(12pad)!: move to handwired/positron/12pad
    QMK review requires handwired boards under keyboards/handwired/
    (qmk/qmk_firmware#26362). Update CI and docs paths accordingly.
    BREAKING CHANGE: build target is now handwired/positron/12pad;
    binaries are named handwired_positron_12pad_<keymap>.bin.

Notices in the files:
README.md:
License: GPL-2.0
